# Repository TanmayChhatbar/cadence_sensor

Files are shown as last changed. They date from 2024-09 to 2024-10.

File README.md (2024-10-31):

# BREAKING FLAW - The BMW output current is insufficient for the ESP32
# (WIP) ESP32 Accelerometer-Based Sensor with Wireless Display Integration
## Overview

This project involves the development of a compact, low-power sensor unit using an ESP32 microcontroller integrated with an accelerometer and powered by a 3.7V LiPo cell, which can be charged using solar energy. The sensor unit wirelessly transmits data over BLE. The system is designed for measuring the cadence when riding a bicycle for live telemetry, with low energy consumption and a tiny form factor.

## Features

- ESP32-Based Sensor Unit: Equipped with an accelerometer to capture motion data.
- Power Options: 3.7V LiPo.
- Charging Options: USB or Solar
- Wireless Data Transmission: Utilizes Bluetooth Low Energy (BLE) for communication between the sensor unit and the display unit.
- Low Power Consumption: Optimized for energy efficiency, suitable for long-term operation on minimal power. The device will go into sleep mode in case of inactivity.

## Components

- ESP32-S3-WROOM-1 Microcontroller: The core of the system, handling both sensor data collection and wireless communication.
- ICM-42670-P Accelerometer: Detects and measures acceleration in three axes.
- BQ25570 BMS: For voltage regulation for the circuit and battery charging.

## Setup and Installation

- Hardware Setup
  - Assemble the ESP32 with the accelerometer and choose either the button cell or solar cell for power.
  - Connect to ESP32 with Bluetooth.

- Software Setup
  - Flash the ESP32 with the provided codebase.
  - The sensor unit will continuously monitor the accelerometer data and send it via BLE to the display unit.
  - The display unit will process and visualize the received data.

## Usage

- The sensor unit will send data, and the display unit will show the live accelerometer readings.

## PCB Design

Below is the image of the PCB design, showcasing the layout of the components for the sensor unit.

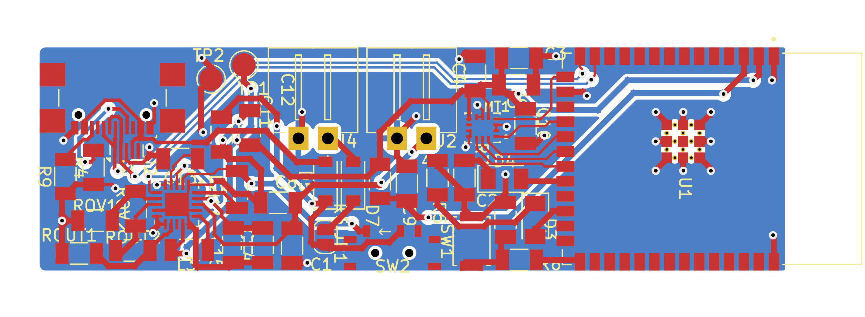
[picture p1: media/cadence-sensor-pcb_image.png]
kicad svg


## Future Improvements

- Integration of additional sensors (e.g., gyroscope).
- Enhanced power management strategies for longer battery life.
- Expansion to support multiple sensor units communicating with a single display.

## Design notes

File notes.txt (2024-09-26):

KiCAD
    ACC_INT RTCGPIO3 is input enabled (IE) at reset. this may not be a problem, but to ensure that this is not an issue, it can be moved to GPIO9 (pin 17)

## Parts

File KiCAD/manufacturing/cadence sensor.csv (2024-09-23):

Reference | Value | Datasheet | Footprint | Qty | DNP
C1,C9 | 1uF | ~ | Capacitor_SMD:C_1206_3216Metric | 2
C2,C4,C15 | 0.1uF | ~ | Capacitor_SMD:C_1206_3216Metric | 3
C3 | 2.2uF | ~ | Capacitor_SMD:C_1206_3216Metric | 1
C5 | 0.01uF | ~ | Capacitor_SMD:C_1206_3216Metric | 1
C8 | 100uF | ~ | Capacitor_SMD:C_1206_3216Metric | 1
C10,C12 | 22uF | ~ | Capacitor_SMD:C_1206_3216Metric | 2
C11,C14 | 4.7uF | ~ | Capacitor_SMD:C_1206_3216Metric | 2
C13 | .01uF | ~ | Capacitor_SMD:C_1206_3216Metric | 1
D3 | LED_G | ~ | Diode_SMD:D_1206_3216Metric | 1
D4 | LED_R | ~ | Diode_SMD:D_1206_3216Metric | 1
D5,D7 | D_Schottky | ~ | Diode_SMD:D_SOD-123 | 2
J1 | USB_C_Receptacle_USB2.0_16P | https://www.usb.org/sites/default/files/documents/usb_type-c.zip | Connector_USB:USB_C_Receptacle_GCT_USB4110 | 1
J2 | JST_BATT | ~ | JST2:JST_XH_S2B-XH-A-1_1x02_P2.50mm_Horizontal_2 | 1
J4 | JST_SOL | ~ | JST2:JST_XH_S2B-XH-A-1_1x02_P2.50mm_Horizontal_2 | 1
L2 | 22uH | ~ | Inductor_SMD:L_1206_3216Metric | 1
L3 | 4.7uH | ~ | Inductor_SMD:L_1206_3216Metric | 1
MT1 | ICM-42670-P |  | ICM_42670_P:XDCR_ICM-42670-P | 1
R4,R9 | 5K1 | ~ | Resistor_SMD:R_1206_3216Metric | 2
R5 | 15R | ~ | Resistor_SMD:R_1206_3216Metric | 1
R6 | 10K | ~ | Resistor_SMD:R_1206_3216Metric | 1
R7 | 68R | ~ | Resistor_SMD:R_1206_3216Metric | 1
R8 | 1K | ~ | Resistor_SMD:R_1206_3216Metric | 1
ROUT1 | 4M7 | ~ | Resistor_SMD:R_1206_3216Metric | 1
ROUT2,ROV2 | 8M2 | ~ | Resistor_SMD:R_1206_3216Metric | 2
ROV1 | 5M1 | ~ | Resistor_SMD:R_1206_3216Metric | 1
SC1 | SM141K05TF (Solar Cell) | ~ |  | 1 | DNP
SW1 | SW_Push | ~ | Button_Switch_SMD:SW_Push_SPST_NO_Alps_SKRK | 1
SW2 | SW_PWR | ~ | switch:switch-MSK-12C02-smd | 1
TP1 | 3V3 | ~ | TestPoint:TestPoint_Pad_D2.0mm | 1
TP2 | GND | ~ | TestPoint:TestPoint_Pad_D2.0mm | 1
U1 | ESP32-S3-WROOM-1-N4 |  | ESP32_S3_WROOM_1_N4:XCVR_ESP32-S3-WROOM-1-N4 | 1
U2 | TPD4E05U06DQA | https://www.ti.com/lit/ds/symlink/tpd4e05u06.pdf | Package_SON:USON-10_2.5x1.0mm_P0.5mm | 1
U7 | BQ25570 | http://www.ti.com/lit/ds/symlink/bq25570.pdf | Package_DFN_QFN:QFN-20-1EP_3.5x3.5mm_P0.5mm_EP2x2mm | 1

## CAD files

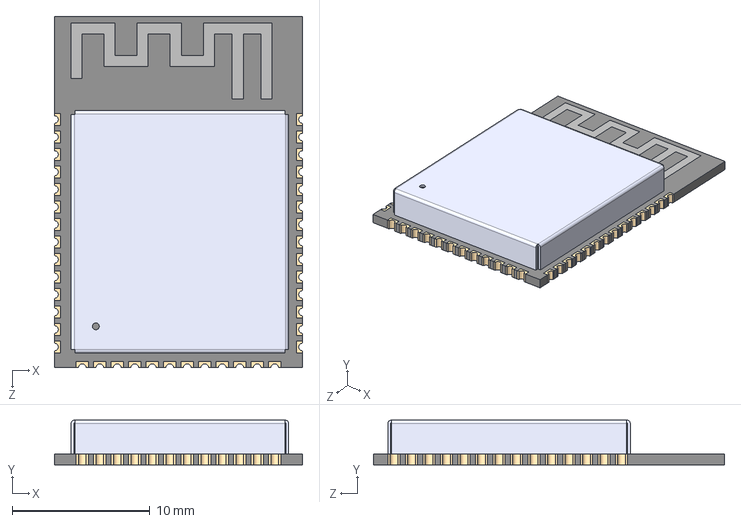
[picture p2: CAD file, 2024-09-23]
KiCAD/downloads/ESP32_S3_WROOM_1_N4/ESP32-S3-WROOM-1-N4.step
18.0 x 3.25 x 25.5 mm

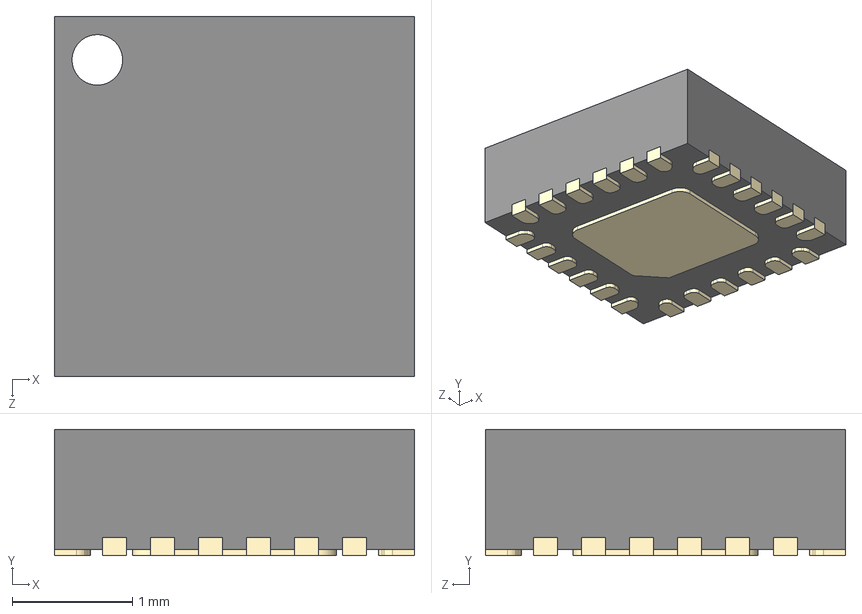
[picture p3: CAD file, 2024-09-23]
KiCAD/downloads/ICM_20948/ICM-20948.step
3.00 x 1.05 x 3.00 mm

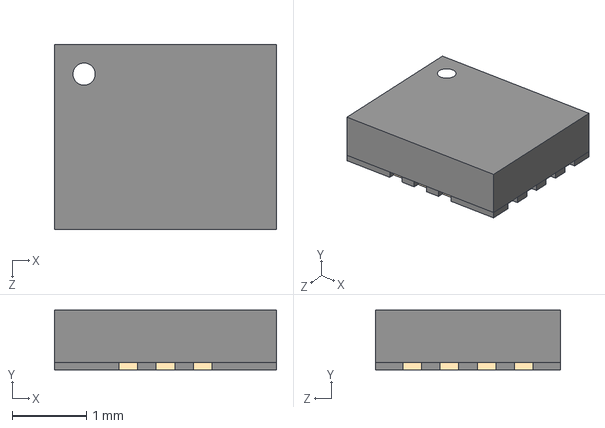
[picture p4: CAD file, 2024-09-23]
KiCAD/downloads/ICM_42670_P/ICM-42670-P.step
3.00 x 0.81 x 2.50 mm

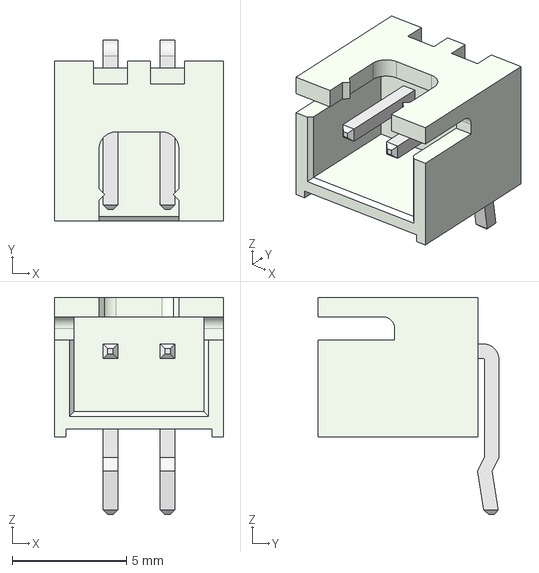
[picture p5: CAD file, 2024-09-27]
KiCAD/downloads/JST_XH_S2B-XH-A-1_1x02_P2.50mm_Horizontal_noback.stp
7.40 x 7.92 x 9.50 mm

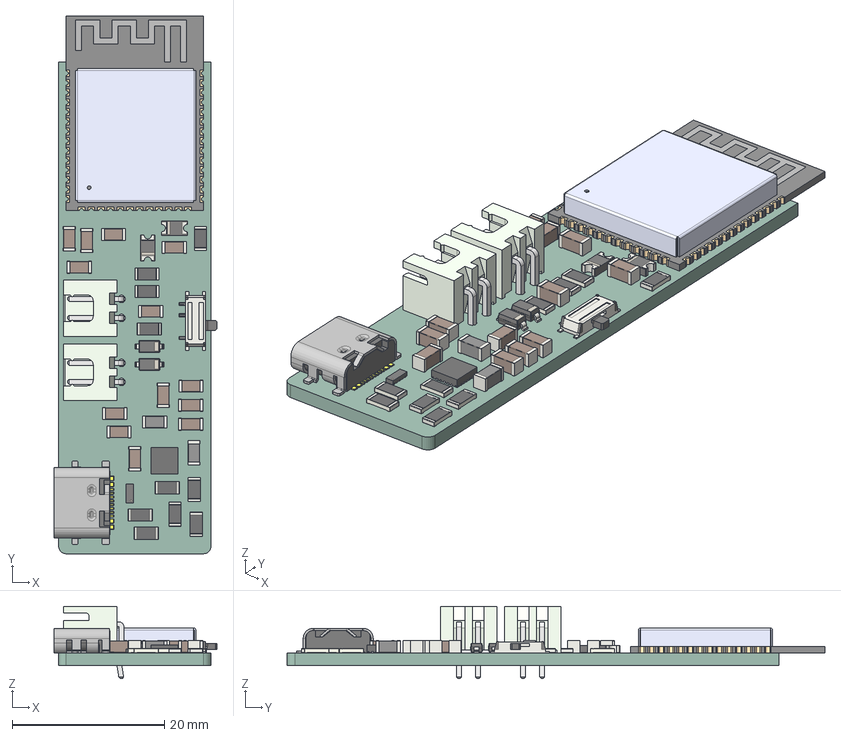
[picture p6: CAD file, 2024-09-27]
NX/cadence sensor - KiCAD export.step
21.4 x 70.5 x 9.50 mm
D_1206 x 2
R_1206_3216Metric x 10
L_1206_3216Metric x 2
C_1206_3216Metric x 13
Fusion_sp
D_SOD_123 x 2
JST_XH_S2B-XH-A-1_1x02_P2.50mm_Horizontal_step x 2
USB_type_C_smd
ESP32-S3-WROOM-1-N8R2
RGR0020A_ASM
USON_10_25x10mm_Pitch05mm
cadence sensor_PCB

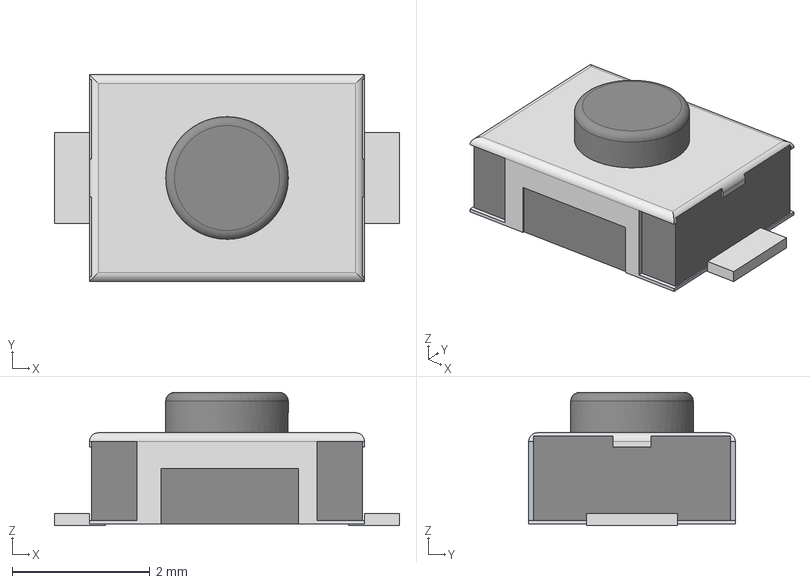
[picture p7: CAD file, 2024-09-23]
KiCAD/downloads/3x4x2mm - 2 Pad.stp
5.00 x 3.00 x 1.93 mm

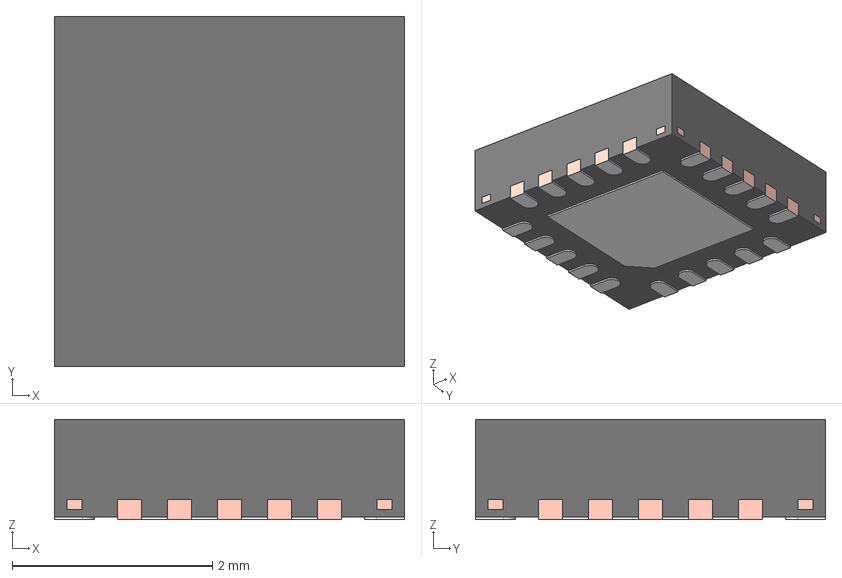
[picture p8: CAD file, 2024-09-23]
KiCAD/downloads/RGR0020A.stp
3.50 x 3.50 x 1.00 mm
FRAME
PIN1_AREA

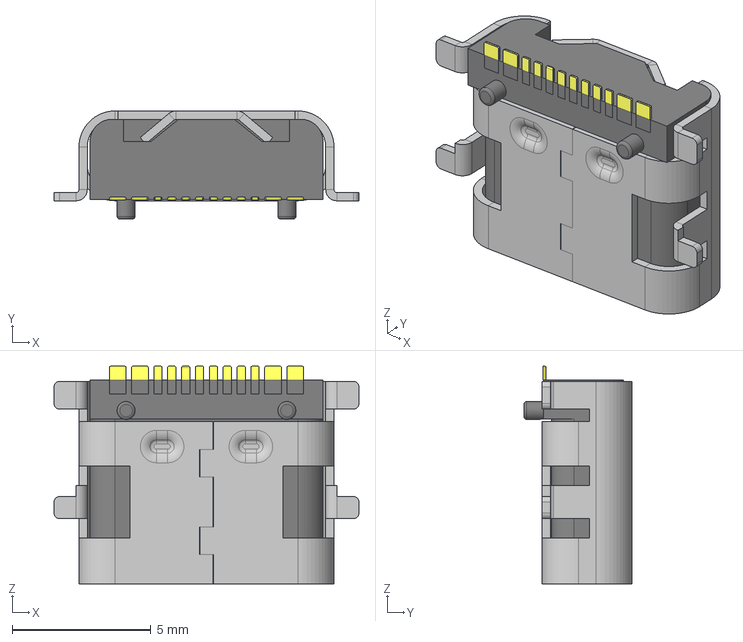
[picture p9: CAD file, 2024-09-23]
KiCAD/downloads/USB_type_C_smd.stp
11.0 x 3.90 x 7.85 mm

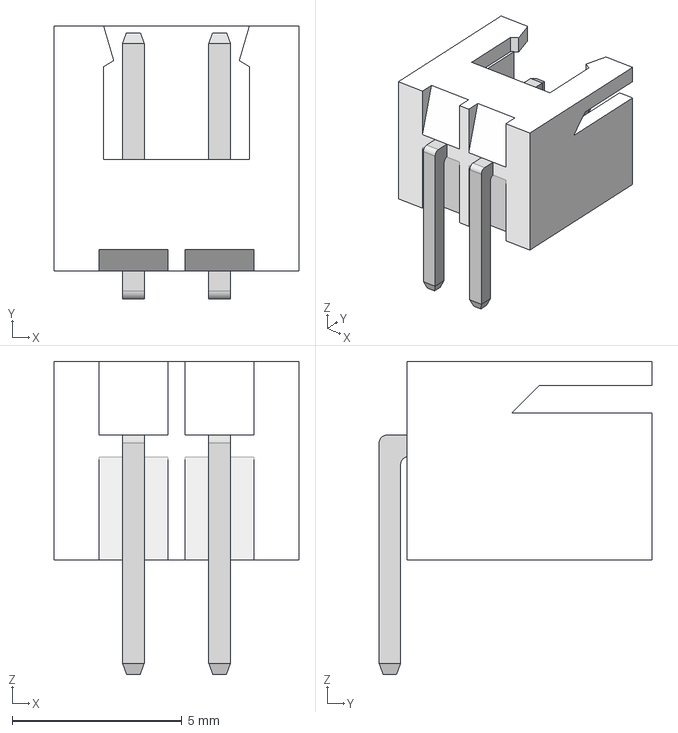
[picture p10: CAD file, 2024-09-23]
KiCAD/downloads/JST - XH - Thru (R) - 2Pin - 2.54mm.stp
7.21 x 8.04 x 9.22 mm

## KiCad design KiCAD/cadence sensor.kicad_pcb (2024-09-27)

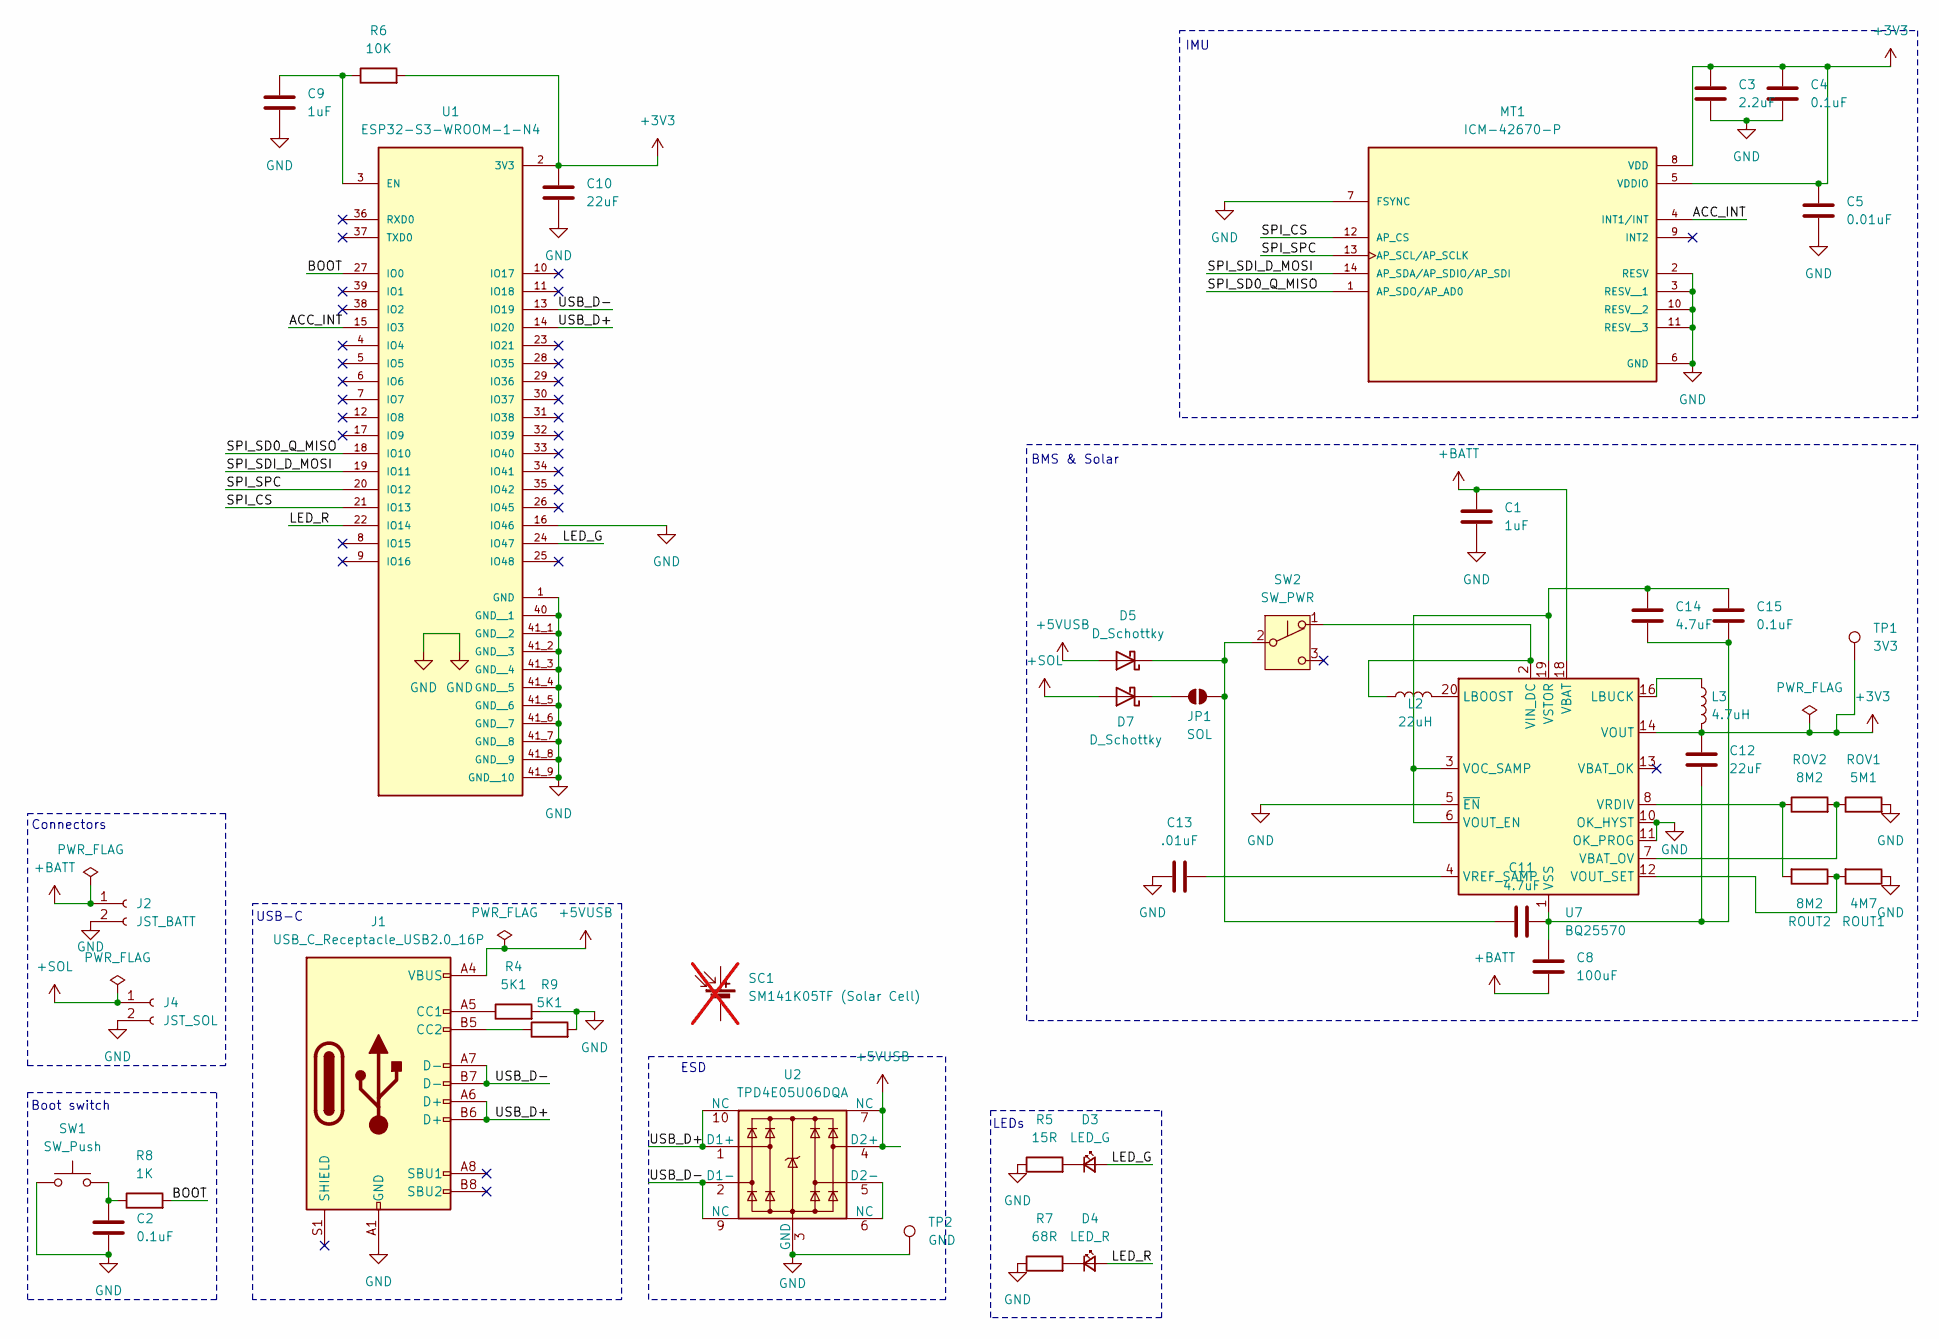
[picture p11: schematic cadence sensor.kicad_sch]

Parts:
C1, C9: 1uF; C_1206_3216Metric
C2, C4, C15: 0.1uF; C_1206_3216Metric
C3: 2.2uF; C_1206_3216Metric
C5: 0.01uF; C_1206_3216Metric
C8: 100uF; C_1206_3216Metric
C10, C12: 22uF; C_1206_3216Metric
C11, C14: 4.7uF; C_1206_3216Metric
C13: .01uF; C_1206_3216Metric
D3: LED_G; D_1206_3216Metric
D4: LED_R; D_1206_3216Metric
D5, D7: D_Schottky; D_SOD-123
J1: USB_C_Receptacle_USB2.0_16P; USB_C_Receptacle_GCT_USB4110
J2: JST_BATT; JST_XH_S2B-XH-A-1_1x02_P2.50mm_Horizontal
J4: JST_SOL; JST_XH_S2B-XH-A-1_1x02_P2.50mm_Horizontal
JP1: SOL; SolderJumper-2_P1.3mm_Open_RoundedPad1.0x1.5mm
L2: 22uH; L_1206_3216Metric
L3: 4.7uH; L_1206_3216Metric
MT1: ICM-42670-P; XDCR_ICM-42670-P; PARTREV 1.1
R4, R9: 5K1; R_1206_3216Metric
R5: 15R; R_1206_3216Metric
R6: 10K; R_1206_3216Metric
R7: 68R; R_1206_3216Metric
R8: 1K; R_1206_3216Metric
ROUT1: 4M7; R_1206_3216Metric
ROUT2: 8M2; R_1206_3216Metric
ROV1: 5M1; R_1206_3216Metric
ROV2: 8M2; R_1206_3216Metric
SC1: SM141K05TF (Solar Cell); not fitted
SW1: SW_Push; SW_Push_SPST_NO_Alps_SKRK
SW2: SW_PWR; switch-MSK-12C02-smd
TP1: 3V3; TestPoint_Pad_D2.0mm
TP2: GND; TestPoint_Pad_D2.0mm
U1: ESP32-S3-WROOM-1-N4; XCVR_ESP32-S3-WROOM-1-N4; PARTREV v1.0
U2: TPD4E05U06DQA; USON-10_2.5x1.0mm_P0.5mm
U7: BQ25570; QFN-20-1EP_3.5x3.5mm_P0.5mm_EP2x2mm

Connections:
+3V3: C3.1, C4.1, C5.1, C10.1, C12.2, L3.2, MT1.5 (VDDIO), MT1.8 (VDD), R6.2, TP1.1, U1.2 (3V3), U7.14 (VOUT)
+5VUSB: D5.2 (A), J1.A4 (VBUS), J1.A9 (VBUS), J1.B4 (VBUS), J1.B9 (VBUS), U2.4 (D2+), U2.7 (NC)
+BATT: C1.1, C8.2, J2.1, U7.18 (VBAT)
+SOL: D7.2 (A), J4.1
/ACC_INT: MT1.4 (INT1/INT), U1.15 (IO3)
/BOOT: R8.2, U1.27 (IO0)
/LED_G: D3.2 (A), U1.24 (IO47)
/LED_R: D4.2 (A), U1.22 (IO14)
/SPI_CS: MT1.12 (AP_CS), U1.21 (IO13)
/SPI_SD0_Q_MISO: MT1.1 (AP_SDO/AP_AD0), U1.18 (IO10)
/SPI_SDI_D_MOSI: MT1.14 (AP_SDA/AP_SDIO/AP_SDI), U1.19 (IO11)
/SPI_SPC: MT1.13 (AP_SCL/AP_SCLK), U1.20 (IO12)
/USB_D+: J1.A6 (D+), J1.B6 (D+), U1.14 (IO20), U2.1 (D1+), U2.10 (NC)
/USB_D-: J1.A7 (D-), J1.B7 (D-), U1.13 (IO19), U2.2 (D1-), U2.9 (NC)
GND: C1.2, C2.2, C3.2, C4.2, C5.2, C9.2, C10.2, C13.1, J1.A1 (GND), J1.A12 (GND), J1.B1 (GND), J1.B12 (GND), J2.2, J4.2, MT1.2 (RESV), MT1.3 (RESV__1), MT1.6 (GND), MT1.7 (FSYNC), MT1.10 (RESV__2), MT1.11 (RESV__3), R4.2, R5.1, R7.1, R9.2, ROUT1.1, ROV1.2, SW1.1, TP2.1, U1.1 (GND), U1.16 (IO46), U1.40 (GND__1), U1.41_1 (GND__2), U1.41_2 (GND__3), U1.41_3 (GND__4), U1.41_4 (GND__5), U1.41_5 (GND__6), U1.41_6 (GND__7), U1.41_7 (GND__8), U1.41_8 (GND__9), U1.41_9 (GND__10), U2.3 (GND), U2.8 (GND), U7.5 (~EN), U7.10 (OK_HYST), U7.11 (OK_PROG)
unnamed: C2.1, R8.1, SW1.2
unnamed: C8.1, C11.2, C12.1, C14.1, C15.1, U7.1 (VSS), U7.9 (VSS), U7.15 (VSS), U7.17 (VSS), U7.21 (VSS)
unnamed: D3.1 (K), R5.2
unnamed: D4.1 (K), R7.2
unnamed: C11.1, D5.1 (K), JP1.2 (B), SW2.2 (B)
unnamed: D7.1 (K), JP1.1 (A)
unnamed: J1.A5 (CC1), R4.1
unnamed: J1.B5 (CC2), R9.1
unnamed: L2.1, SW2.1 (A), U7.2 (VIN_DC)
unnamed: C9.1, R6.1, U1.3 (EN)
unnamed: U2.5 (D2-), U2.6 (NC)
unnamed: L2.2, U7.20 (LBOOST)
unnamed: L3.1, U7.16 (LBUCK)
unnamed: ROV1.1, ROV2.2, U7.7 (VBAT_OV)
unnamed: C14.2, C15.2, U7.3 (VOC_SAMP), U7.6 (VOUT_EN), U7.19 (VSTOR)
unnamed: ROUT1.2, ROUT2.1, U7.12 (VOUT_SET)
unnamed: ROUT2.2, ROV2.1, U7.8 (VRDIV)
unnamed: C13.2, U7.4 (VREF_SAMP)

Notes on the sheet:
LEDs
BMS & Solar
Boot switch
ESD
Connectors
IMU
USB-C

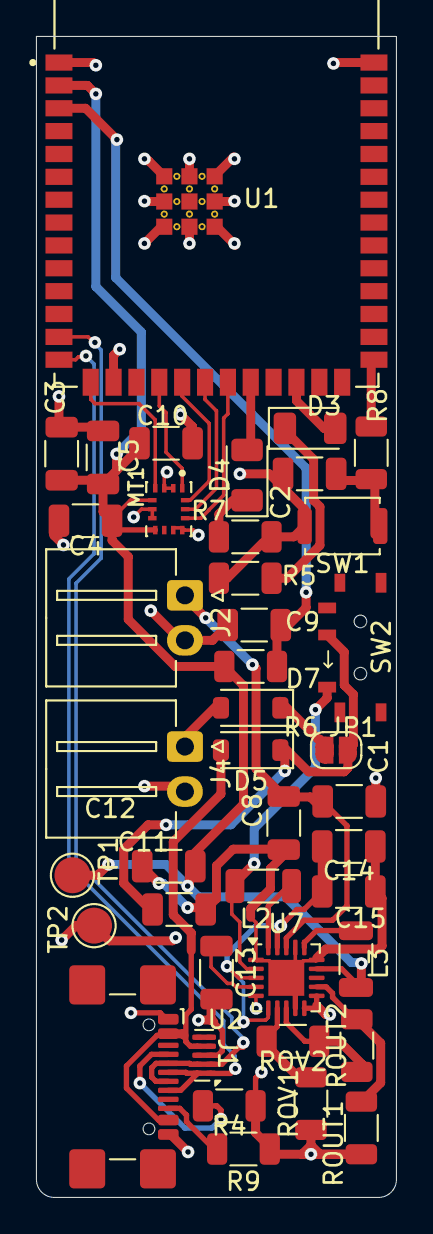
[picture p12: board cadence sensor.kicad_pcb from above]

Board: 2 copper layers, 20.0 x 64.5 mm, 41 parts (0 on the bottom side), 33 nets.

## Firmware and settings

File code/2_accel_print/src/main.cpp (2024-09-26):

#include <Arduino.h>
#include "pindef.h"
#include "ICM42670P.h"
#include "esp_sleep.h"
#include "utils.h"

void setup() {
  Serial.begin(115200);
  icmSetup();   // setup SPI and IMU
  xTaskCreate(routine, "normal_operation", 128, NULL, 1, &normalOP);  // create routine task for reading and analysing acc data
  vTaskStartScheduler();
}

void loop() {
  delay(1e3); // do nothing in loop. task scheduler will handle everything
}

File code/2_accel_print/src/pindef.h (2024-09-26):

#define LED_G GPIO_NUM_47
#define LED_R GPIO_NUM_14

#define SPI_SPC GPIO_NUM_10      // clock
#define SPI_MISO GPIO_NUM_11     // master out slave in
#define SPI_MOSI GPIO_NUM_12     // master in slave out 
#define SPI_CS  GPIO_NUM_13      // chip select

#define ACC_INT GPIO_NUM_3       // accelerometer interrupt

#define BOOT GPIO_NUM_0

#define USB_DP GPIO_NUM_20       // USB_D+
#define USB_DN GPIO_NUM_19       // USB_D-

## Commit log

2024-09-23 add all files
    [3x4x2mm - 2 Pad.stp, Calc.xlsx, ESP32-S3-WROOM-1-N4.step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]
2024-09-26 added nominal accelerometer. compiled, not tested
2024-09-26 KiCAD use local modified of footprint for JST connector
    [cadence sensor.kicad_pcb, cadence sensor.kicad_sch]
2024-09-26 move KiCAD downloads to its folder
    [3x4x2mm - 2 Pad.stp, ESP32-S3-WROOM-1-N4.step, ICM-20948.step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]
2024-09-26 remove KiCAD backup files
    [cadence sensor - unused.kicad_pcb, cadence sensor - unused.kicad_sch]
2024-09-26 rename pcb image in media folder and its reference in README
2024-09-26 update gitignore for KiCAD files
2024-09-26 move printed.zip to releases
2024-09-26 moved excel to misc
    [Calc.xlsx]
2024-09-26 ignore KiCAD lock files while editing
2024-09-26 ignore KiCAD locked files on edit - update
2024-09-27 CAD changes in KiCAD 3d model
    [JST_XH_S2B-XH-A-1_1x02_P2.50mm_Horizontal_noback.stp, cadence sensor.kicad_pcb]
2024-09-27 add step file for PCB
    [cadence sensor - KiCAD export.step]
2024-09-27 save KiCAD
2024-10-07 found issue in PCB design
    [cadence sensor.kicad_sch]
